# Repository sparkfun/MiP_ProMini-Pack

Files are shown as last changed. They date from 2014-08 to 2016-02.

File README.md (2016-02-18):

SparkFun MiP ProMini-Pack
===========================

SparkFun MiP ProMini-Pack

[*SparkFun MiP ProMini-Pack (DEV-13058)*](https://www.sparkfun.com/products/13058)

The MiP Robotic Platform is the first self-balancing robot that you can drive, dance, plays games, battle with other MiPs, and that you can control via a compatible iOS or Android device. 
With the SparkFun ProMini-Pack you can access the robot’s built-in hacking port to add increased functionality and a miniature Arduino to your MiP. 

Repository Contents
-------------------

* **/Hardware** - Eagle design files (.brd, .sch)
* **/Libraries** - Libraries for use with the <PRODUCT NAME>
* **/Production** - Production panel files (.brd)

Documentation
--------------
* **[Library](https://github.com/sparkfun/SparkFun_MiP_Arduino_Library)** - Arduino library for the MiP ProMini-Pack.
* **[Hookup Guide](https://learn.sparkfun.com/tutorials/hacking-the-mip---promini-pack)** - Basic hookup guide for the MiP ProMini-Pack.
* **[SparkFun Fritzing repo](https://github.com/sparkfun/Fritzing_Parts)** - Fritzing diagrams for SparkFun products.
* **[SparkFun 3D Model repo](https://github.com/sparkfun/3D_Models)** - 3D models of SparkFun products. 
* **[SparkFun Graphical Datasheets](https://github.com/sparkfun/Graphical_Datasheets)** -Graphical Datasheets for various SparkFun products.

License Information
-------------------

This product is _**open source**_! 

Please review the LICENSE.md file for license information. 

If you have any questions or concerns on licensing, please contact techsupport@sparkfun.com.

Distributed as-is; no warranty is given.

- Your friends at SparkFun.

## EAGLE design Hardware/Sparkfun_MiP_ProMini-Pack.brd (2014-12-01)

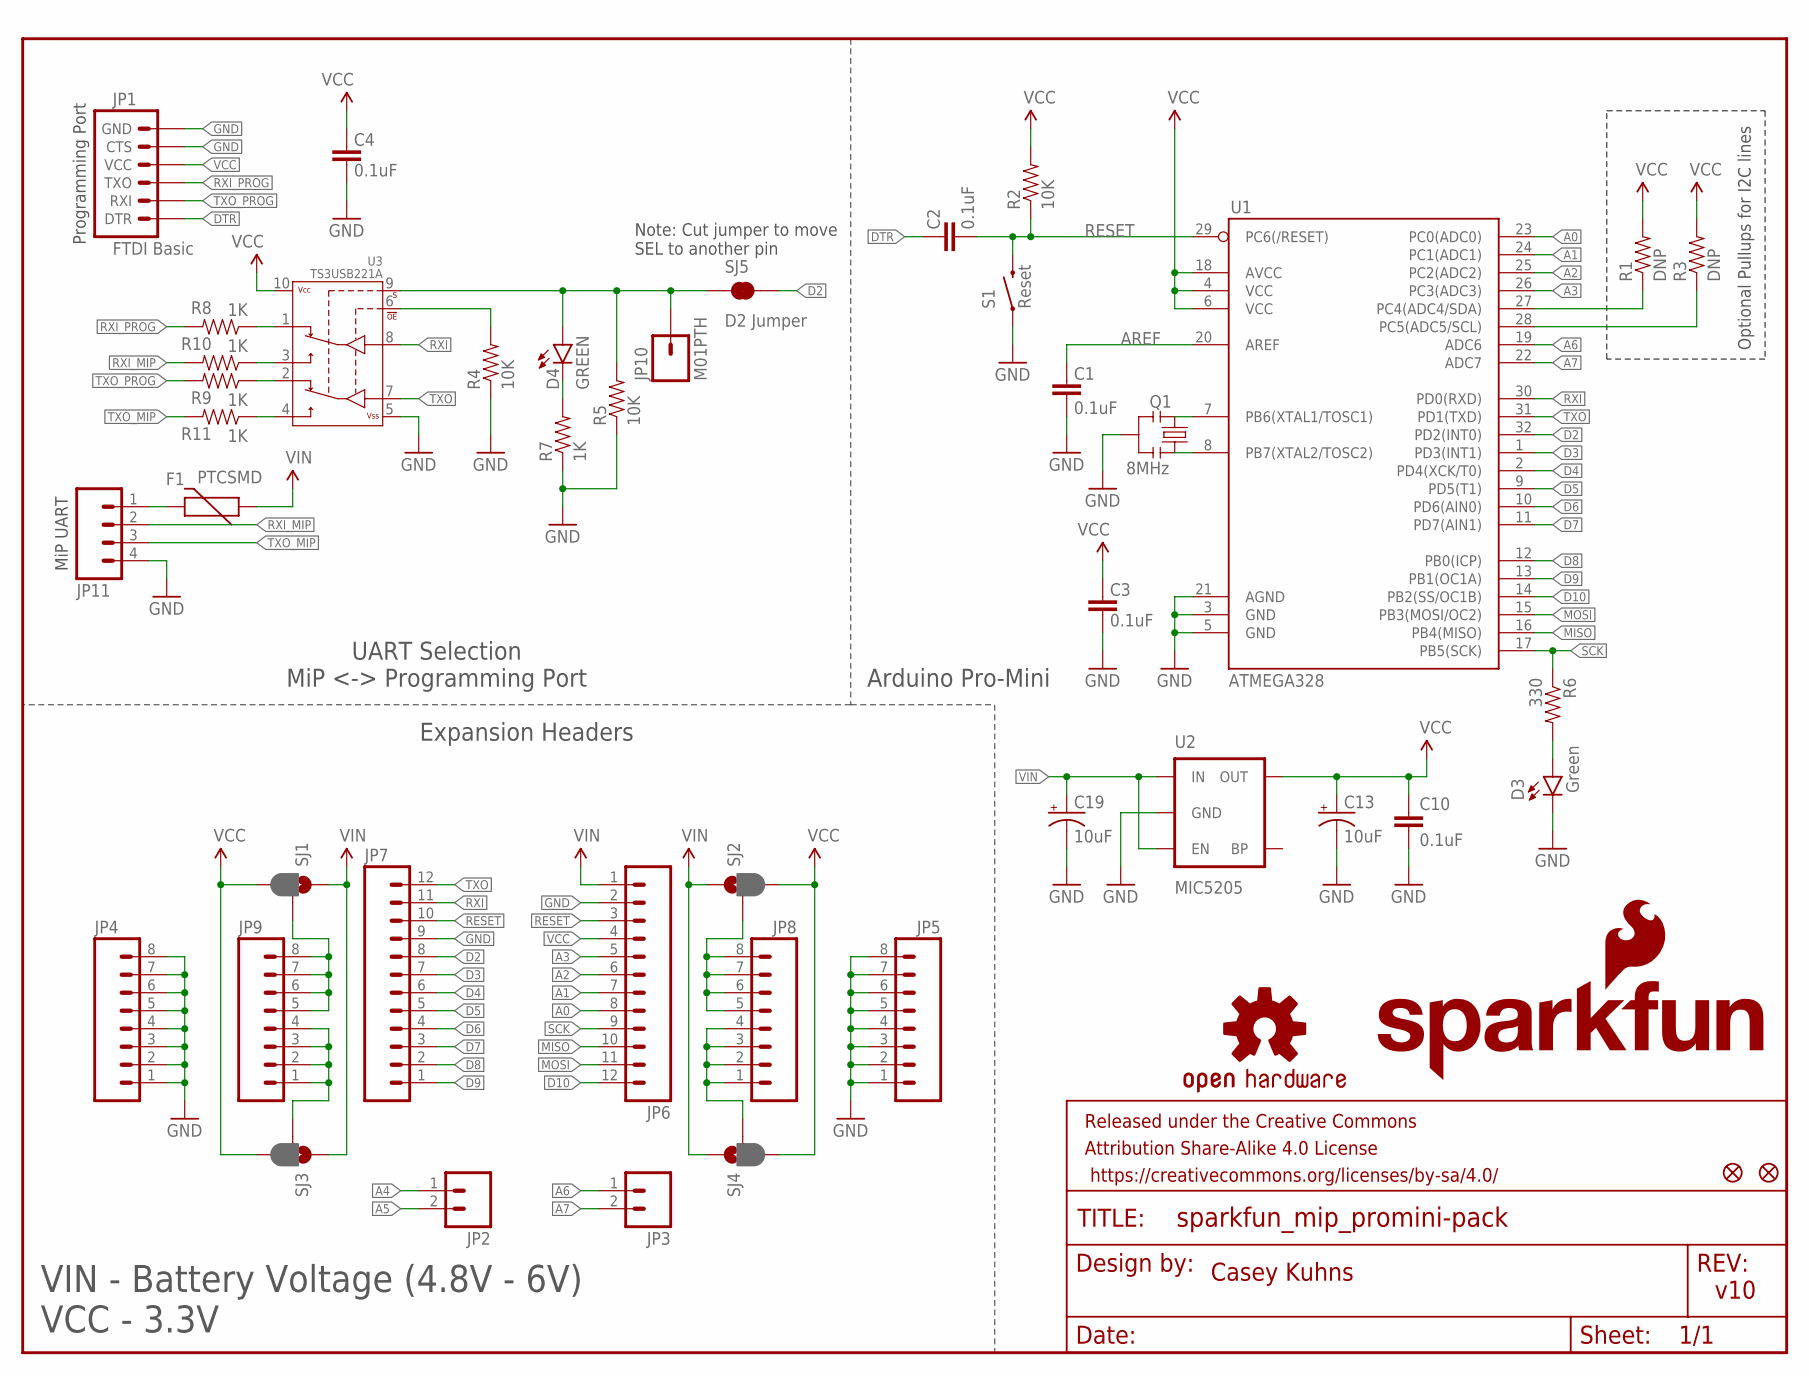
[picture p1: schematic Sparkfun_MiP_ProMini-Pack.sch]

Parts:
C1, C2, C3, C4, C10: 0.1uF; 0603-CAP
C13, C19: 10uF; EIA3216
D3: Green; LED-0603
D4: GREEN; LED-0603
F1: PTCSMD; PTC-1206
FID1, FID2: FIDUCIAL1X2; FIDUCIAL-1X2
FRAME1: FRAME-LETTER; CREATIVE_COMMONS
JP1: FTDI Basic; 1X06
JP2, JP3: M02PTH; 1X02
JP4, JP5, JP8, JP9: M081X08; 1X08
JP6, JP7: M12PTH; 1X12
JP10: M01PTH; 1X01
JP11: M04JST; 1X04-1.5MM_JST
LOGO1: SFE_LOGO_NAME_FLAME.1_INCH; SFE_LOGO_NAME_FLAME_.1
LOGO2: OSHW-LOGOS; OSHW-LOGO-S
Q1: 8MHz; RESONATOR-SMD
R1, R3: DNP; 0603-RES
R2, R4, R5: 10K; 0603-RES
R6: 330; 0603-RES
R7, R8, R9, R10, R11: 1K; 0603-RES
S1: Reset; TACTILE-SWITCH-SMD
SJ1, SJ2, SJ3, SJ4: JUMPER-PAD-3-2OF3_NC_BY_PASTE; PAD-JUMPER-3-2OF3_NC_BY_PASTE_YES_SILK_FULL_BOX
SJ5: D2 Jumper; PAD-JUMPER-2-NC_BY_TRACE_YES_SILK
U1: ATMEGA328; TQFP32-08
U2: MIC5205; SOT23-5
U3: TS3USB221A; QFN-10-RSE

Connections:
A0: JP6.8, U1.23 (PC0(ADC0))
A1: JP6.7, U1.24 (PC1(ADC1))
A2: JP6.6, U1.25 (PC2(ADC2))
A3: JP6.5, U1.26 (PC3(ADC3))
A4: JP2.1, R1.1, U1.27 (PC4(ADC4/SDA))
A5: JP2.2, R3.1, U1.28 (PC5(ADC5/SCL))
A6: JP3.1, U1.19 (ADC6)
A7: JP3.2, U1.22 (ADC7)
AREF: C1.2, U1.20 (AREF)
D2: JP7.8, SJ5.2, U1.32 (PD2(INT0))
D3: JP7.7, U1.1 (PD3(INT1))
D4: JP7.6, U1.2 (PD4(XCK/T0))
D5: JP7.5, U1.9 (PD5(T1))
D6: JP7.4, U1.10 (PD6(AIN0))
D7: JP7.3, U1.11 (PD7(AIN1))
D8: JP7.2, U1.12 (PB0(ICP))
D9: JP7.1, U1.13 (PB1(OC1A))
D10: JP6.12, U1.14 (PB2(SS/OC1B))
DTR: C2.2, JP1.1 (DTR)
GND: C1.1, C3.1, C4.1, C10.2, C13.C (-), C19.C (-), D3.C, JP1.5 (CTS), JP1.6 (GND), JP4.1, JP4.2, JP4.3, JP4.4, JP4.5, JP4.6, JP4.7, JP4.8, JP5.1, JP5.2, JP5.3, JP5.4, JP5.5, JP5.6, JP5.7, JP5.8, JP6.2, JP7.9, JP11.4, Q1.2, R4.1, R5.1, R7.1, S1.1, U1.3 (GND), U1.5 (GND), U1.21 (AGND), U2.2 (GND), U3.5 (VSS)
MISO: JP6.10, U1.16 (PB4(MISO))
MOSI: JP6.11, U1.15 (PB3(MOSI/OC2))
unnamed: Q1.3, U1.8 (PB7(XTAL2/TOSC2))
unnamed: JP9.5, JP9.6, JP9.7, JP9.8, SJ1.2
unnamed: JP9.1, JP9.2, JP9.3, JP9.4, SJ3.2
unnamed: Q1.1, U1.7 (PB6(XTAL1/TOSC1))
unnamed: JP8.5, JP8.6, JP8.7, JP8.8, SJ2.2
unnamed: JP8.1, JP8.2, JP8.3, JP8.4, SJ4.2
unnamed: D3.A, R6.2
unnamed: D4.C, R7.2
unnamed: R10.1, U3.3 (2D+)
unnamed: R11.1, U3.4 (2D-)
unnamed: R8.1, U3.1 (1D+)
unnamed: R4.2, U3.6 (!OE)
unnamed: R9.1, U3.2 (1D-)
unnamed: F1.2, JP11.1
RESET: C2.1, JP6.3, JP7.10, R2.1, S1.3 (2), U1.29 (PC6(/RESET))
RXI: JP7.11, U1.30 (PD0(RXD)), U3.8 (D+)
RXI_MIP: JP11.2, R10.2
RXI_PROG: JP1.3 (TXO), R8.2
SCK: JP6.9, R6.1, U1.17 (PB5(SCK))
SELECT: D4.A, JP10.1, R5.2, SJ5.1, U3.9 (S)
TXO: JP7.12, U1.31 (PD1(TXD)), U3.7 (D-)
TXO_MIP: JP11.3, R11.2
TXO_PROG: JP1.2 (RXI), R9.2
VCC: C3.2, C4.2, C10.1, C13.A (+), JP1.4 (VCC), JP6.4, R1.2, R2.2, R3.2, SJ1.3, SJ2.3, SJ3.3, SJ4.3, U1.4 (VCC), U1.6 (VCC), U1.18 (AVCC), U2.5 (OUT), U3.10 (VCC)
VIN: C19.A (+), F1.1, JP6.1, SJ1.1, SJ2.1, SJ3.1, SJ4.1, U2.1 (IN), U2.3 (EN)

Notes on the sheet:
Optional Pullups for I2C lines
Casey Kuhns
v10
Note: Cut jumper to move SEL to another pin
MiP UART
Programming Port
UART Selection MiP <-> Programming Port
Expansion Headers
Arduino Pro-Mini
VIN - Battery Voltage (4.8V - 6V) VCC - 3.3V

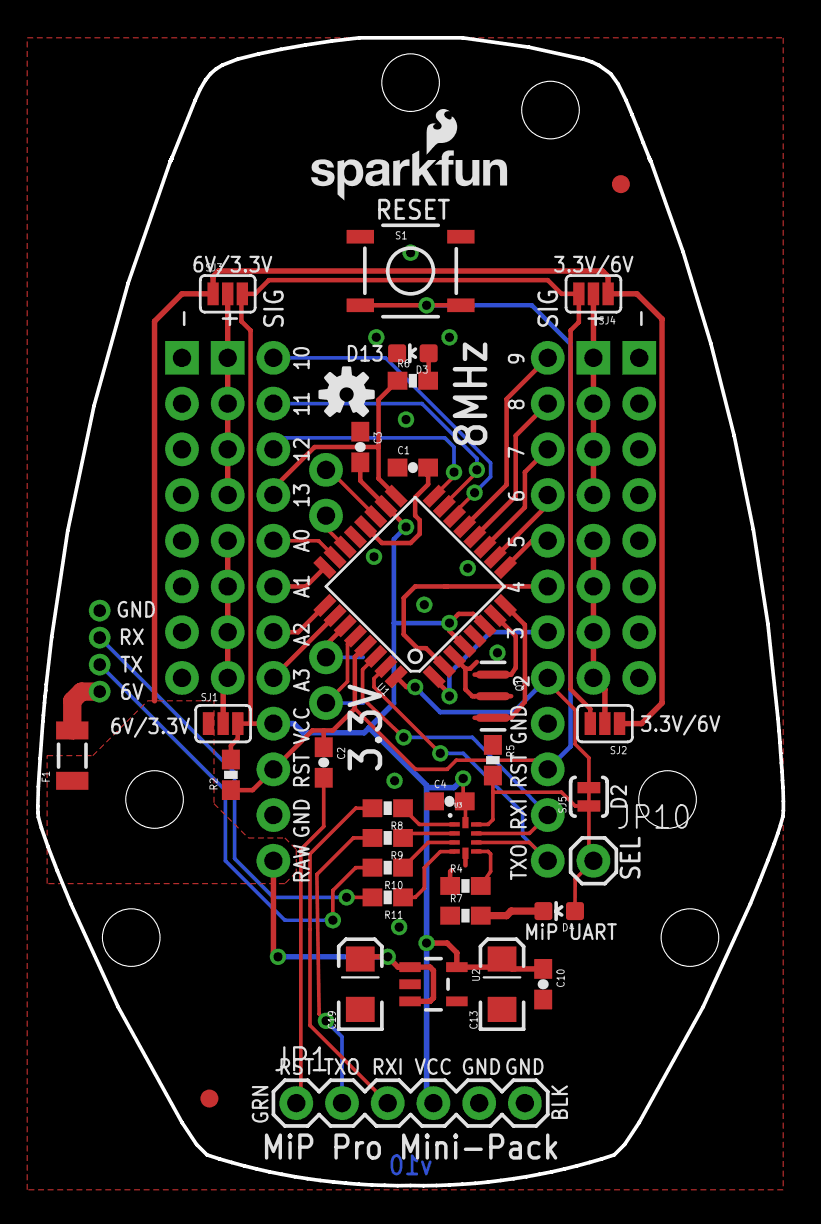
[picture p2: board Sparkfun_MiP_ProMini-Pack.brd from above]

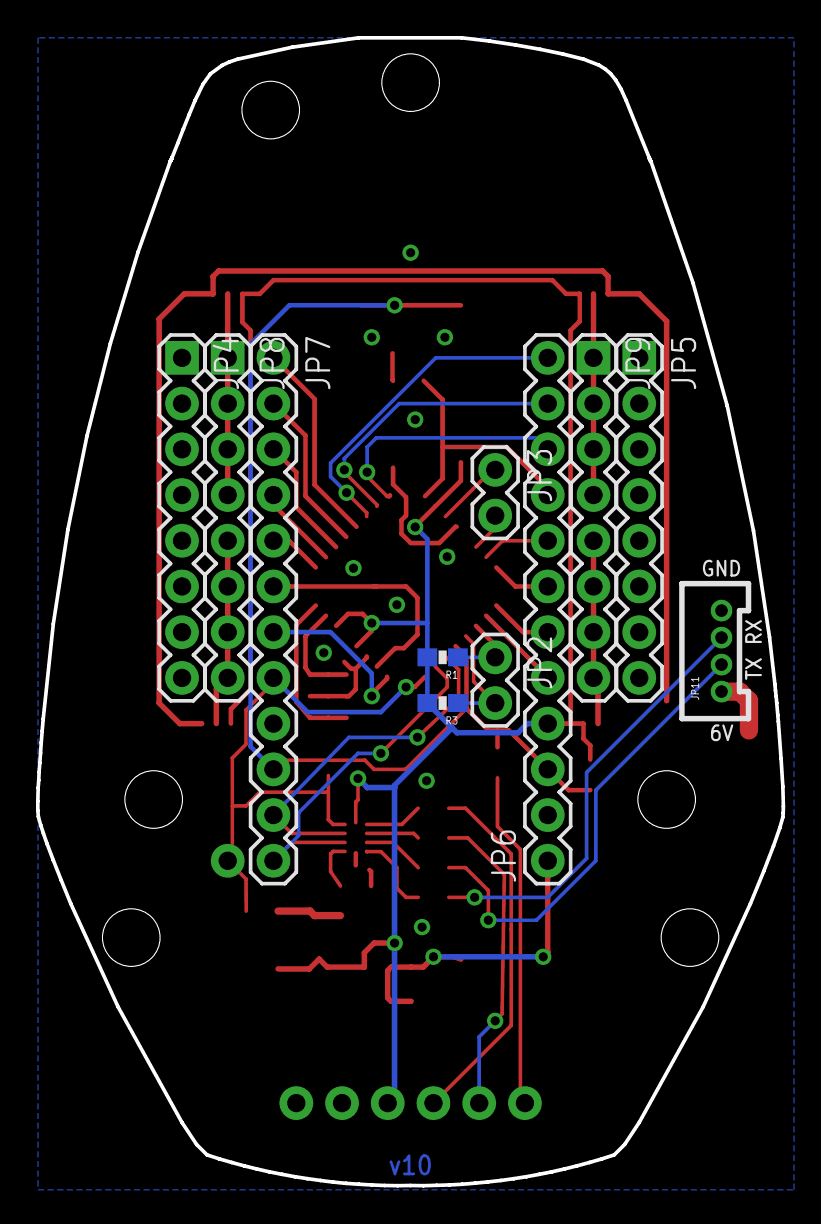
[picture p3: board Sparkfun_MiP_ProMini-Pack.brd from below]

Board: 2 copper layers, 41.4 x 63.8 mm, 47 parts (11 on the bottom side), 47 nets.

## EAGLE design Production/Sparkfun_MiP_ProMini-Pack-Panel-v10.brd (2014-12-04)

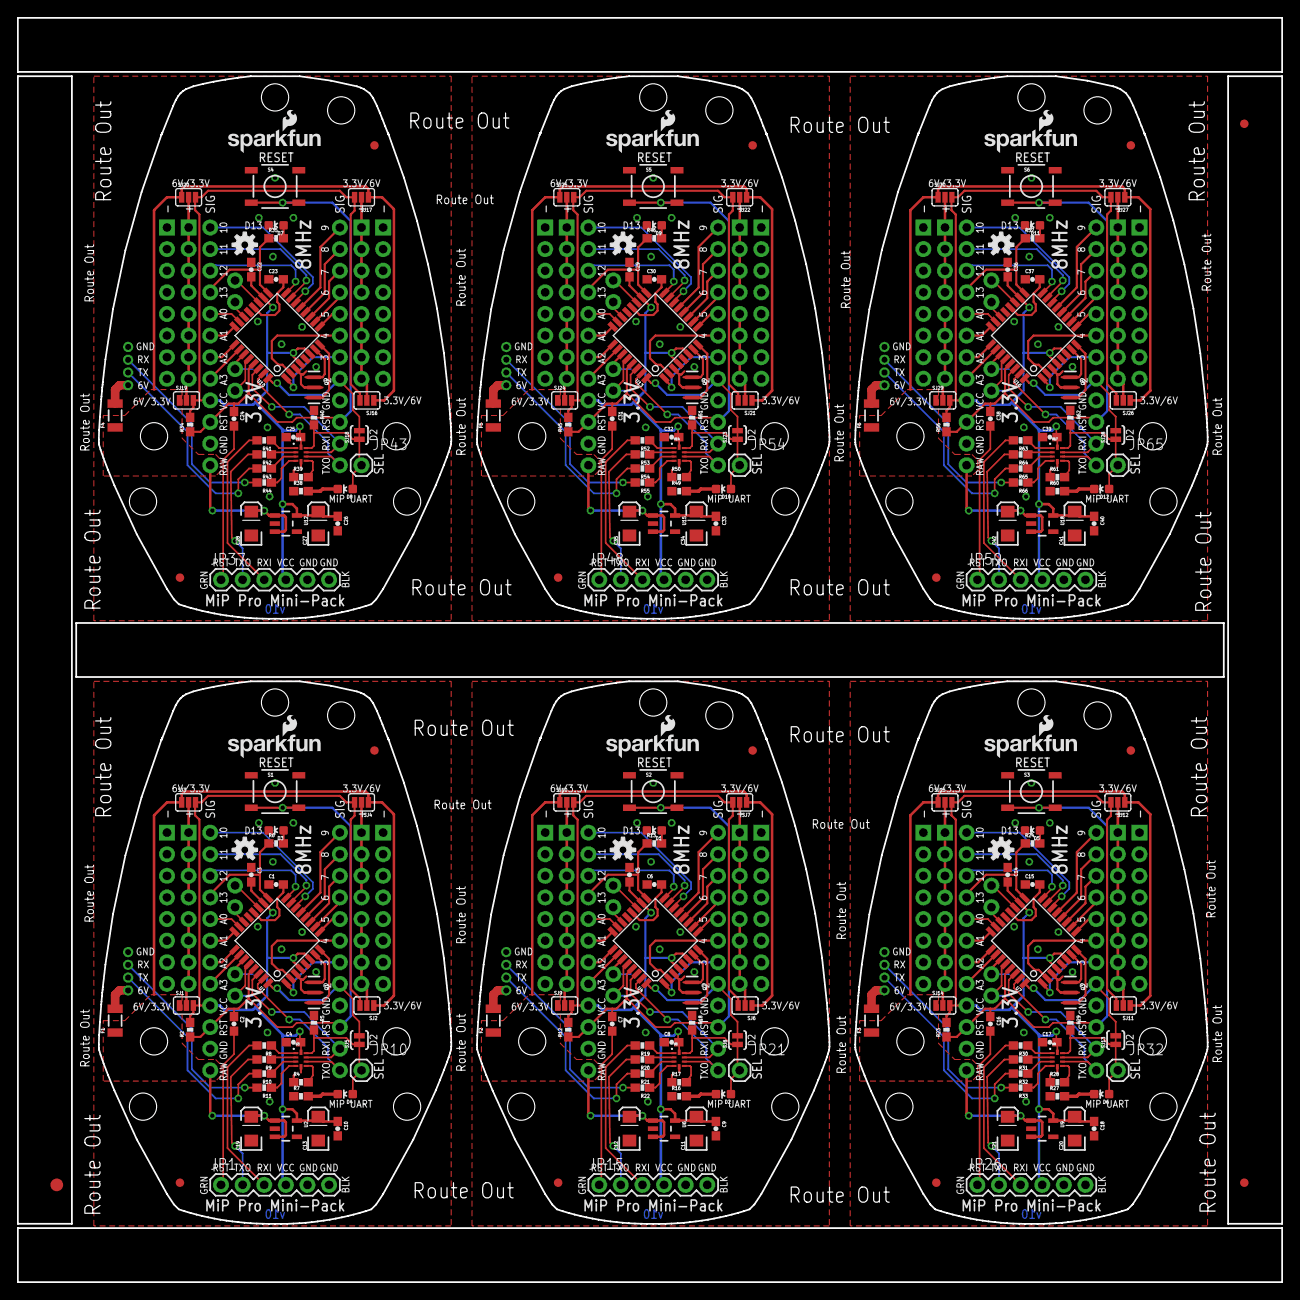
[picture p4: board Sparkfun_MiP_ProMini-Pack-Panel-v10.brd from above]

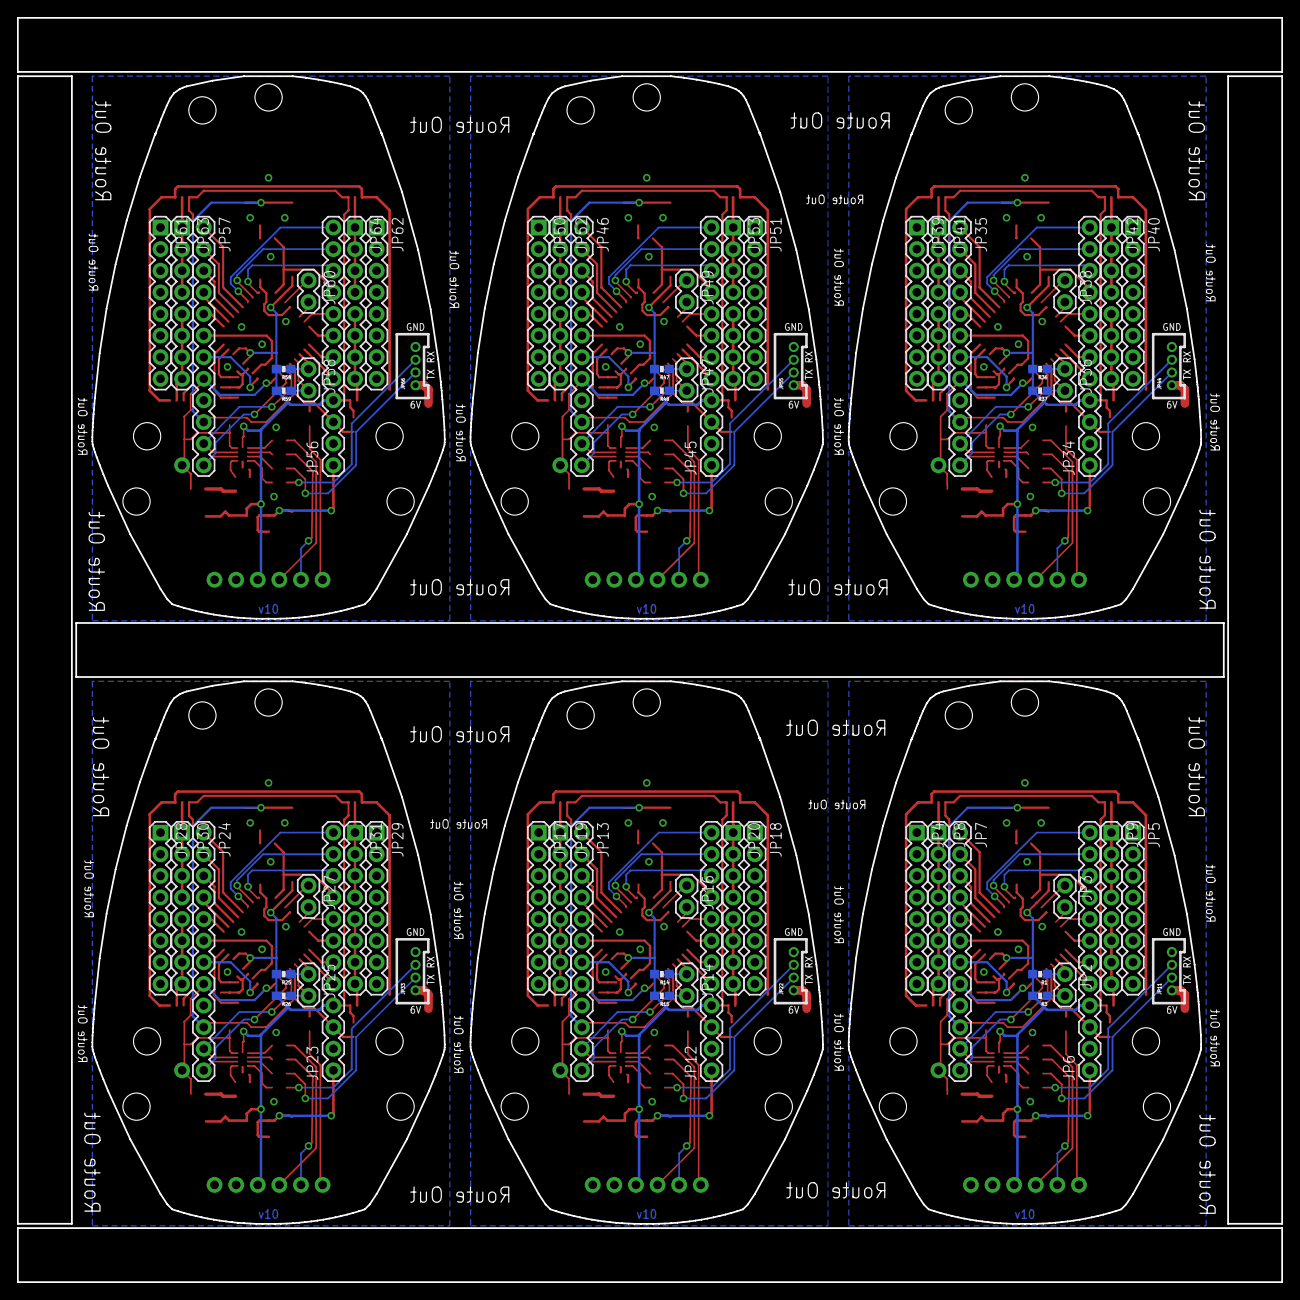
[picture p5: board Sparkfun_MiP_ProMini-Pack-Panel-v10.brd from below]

Board: 2 copper layers, 148.6 x 148.6 mm, 279 parts (66 on the bottom side), 282 nets.

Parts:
C1, C2, C3, C4, C5, C6, C7, C8, C9, C10, C14, C15, C16, C17, C18, C22, C23, C24, C25, C26, C29, C30, C31, C32, C33, C36, C37, C38, C39, C40: 0.1uF; 0603-CAP
C11, C12, C13, C19, C20, C21, C27, C28, C34, C35, C41, C42: 10uF; EIA3216
D1, D3, D5, D7, D9, D11: Green; LED-0603
D2, D4, D6, D8, D10, D12: GREEN; LED-0603
E$1: FIDUCIAL-1.5X3
E$4, E$10: FIDUCIAL-1X2
F1, F2, F3, F4, F5, F6: PTCSMD; PTC-1206
FID1, FID2, FID3, FID4, FID5, FID6, FID7, FID8, FID9, FID10, FID11, FID12: FIDUCIAL1X2; FIDUCIAL-1X2
JP1, JP15, JP26, JP37, JP48, JP59: FTDI Basic; 1X06
JP2, JP3, JP14, JP16, JP25, JP27, JP36, JP38, JP47, JP49, JP58, JP60: 1X02
JP4, JP5, JP8, JP9, JP17, JP18, JP19, JP20, JP28, JP29, JP30, JP31, JP39, JP40, JP41, JP42, JP50, JP51, JP52, JP53, JP61, JP62, JP63, JP64: 1X08
JP6, JP7, JP12, JP13, JP23, JP24, JP34, JP35, JP45, JP46, JP56, JP57: 1X12
JP10, JP21, JP32, JP43, JP54, JP65: M01PTH; 1X01
JP11, JP22, JP33, JP44, JP55, JP66: 1X04-1.5MM_JST
LOGO1, LOGO3, LOGO5, LOGO7, LOGO9, LOGO11: SFE_LOGO_NAME_FLAME.1_INCH; SFE_LOGO_NAME_FLAME_.1
LOGO2, LOGO4, LOGO6, LOGO8, LOGO10, LOGO12: OSHW-LOGOS; OSHW-LOGO-S
Q1, Q2, Q3, Q4, Q5, Q6: 8MHz; RESONATOR-SMD
R1, R3, R14, R15, R25, R26, R36, R37, R47, R48, R58, R59: DNP; 0603-RES
R2, R4, R5, R12, R17, R18, R23, R28, R29, R34, R39, R40, R45, R50, R51, R56, R61, R62: 10K; 0603-RES
R6, R13, R24, R35, R46, R57: 330; 0603-RES
R7, R8, R9, R10, R11, R16, R19, R20, R21, R22, R27, R30, R31, R32, R33, R38, R41, R42, R43, R44, R49, R52, R53, R54, R55, R60, R63, R64, R65, R66: 1K; 0603-RES
S1, S2, S3, S4, S5, S6: Reset; TACTILE-SWITCH-SMD
SJ1, SJ2, SJ3, SJ4, SJ6, SJ7, SJ9, SJ10, SJ11, SJ12, SJ14, SJ15, SJ16, SJ17, SJ19, SJ20, SJ21, SJ22, SJ24, SJ25, SJ26, SJ27, SJ29, SJ30: PAD-JUMPER-3-2OF3_NC_BY_PASTE_YES_SILK_FULL_BOX
SJ5, SJ8, SJ13, SJ18, SJ23, SJ28: D2 Jumper; PAD-JUMPER-2-NC_BY_TRACE_YES_SILK
U1, U4, U7, U10, U13, U16: ATMEGA328; TQFP32-08
U2, U6, U9, U12, U15, U18: MIC5205; SOT23-5
U3, U5, U8, U11, U14, U17: TS3USB221A; QFN-10-RSE

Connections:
A0: JP6.8, U1.23
A1: JP6.7, U1.24
A2: JP6.6, U1.25
A3: JP6.5, U1.26
A4: JP2.1, R1.1, U1.27
A5: JP2.2, R3.1, U1.28
A6: JP3.1, U1.19
A7: JP3.2, U1.22
A8: JP14.2, R15.1, U4.28
A9: JP14.1, R14.1, U4.27
A10: JP12.5, U4.26
A11: JP12.6, U4.25
A12: JP12.7, U4.24
A13: JP12.8, U4.23
A14: JP16.1, U4.19
A15: JP16.2, U4.22
A16: JP25.2, R26.1, U7.28
A17: JP25.1, R25.1, U7.27
A18: JP23.5, U7.26
A19: JP23.6, U7.25
A20: JP23.7, U7.24
A21: JP23.8, U7.23
A22: JP27.1, U7.19
A23: JP27.2, U7.22
A24: JP36.2, R37.1, U10.28
A25: JP36.1, R36.1, U10.27
A26: JP34.5, U10.26
A27: JP34.6, U10.25
A28: JP34.7, U10.24
A29: JP34.8, U10.23
A30: JP38.1, U10.19
A31: JP38.2, U10.22
A32: JP47.2, R48.1, U13.28
A33: JP47.1, R47.1, U13.27
A34: JP45.5, U13.26
A35: JP45.6, U13.25
A36: JP45.7, U13.24
A37: JP45.8, U13.23
A38: JP49.1, U13.19
A39: JP49.2, U13.22
A40: JP58.2, R59.1, U16.28
A41: JP58.1, R58.1, U16.27
A42: JP56.5, U16.26
A43: JP56.6, U16.25
A44: JP56.7, U16.24
A45: JP56.8, U16.23
A46: JP60.1, U16.19
A47: JP60.2, U16.22
AREF: C1.2, U1.20
AREF1: C6.2, U4.20
AREF2: C15.2, U7.20
AREF3: C23.2, U10.20
AREF4: C30.2, U13.20
AREF5: C37.2, U16.20
D1: JP13.1, U4.13
D2: JP7.8, SJ5.2, U1.32
D3: JP7.7, U1.1
D4: JP7.6, U1.2
D5: JP7.5, U1.9
D6: JP7.4, U1.10
D7: JP7.3, U1.11
D8: JP7.2, U1.12
D9: JP7.1, U1.13
D10: JP6.12, U1.14
D11: JP13.2, U4.12
D12: JP13.8, SJ8.2, U4.32
D13: JP13.7, U4.1
D14: JP13.6, U4.2
D15: JP13.5, U4.9
D16: JP13.4, U4.10
D17: JP13.3, U4.11
D18: JP12.12, U4.14
D19: JP24.1, U7.13
D20: JP24.2, U7.12
D21: JP24.8, SJ13.2, U7.32
D22: JP24.7, U7.1
D23: JP24.6, U7.2
D24: JP24.5, U7.9
D25: JP24.4, U7.10
D26: JP24.3, U7.11
D27: JP23.12, U7.14
D28: JP35.1, U10.13
D29: JP35.2, U10.12
D30: JP35.8, SJ18.2, U10.32
D31: JP35.7, U10.1
D32: JP35.6, U10.2
D33: JP35.5, U10.9
D34: JP35.4, U10.10
D35: JP35.3, U10.11
D36: JP34.12, U10.14
D37: JP46.1, U13.13
D38: JP46.2, U13.12
D39: JP46.8, SJ23.2, U13.32
D40: JP46.7, U13.1
D41: JP46.6, U13.2
D42: JP46.5, U13.9
D43: JP46.4, U13.10
D44: JP46.3, U13.11
D45: JP45.12, U13.14
D46: JP57.1, U16.13
D47: JP57.2, U16.12
D48: JP57.8, SJ28.2, U16.32
D49: JP57.7, U16.1
D50: JP57.6, U16.2
D51: JP57.5, U16.9
D52: JP57.4, U16.10
D53: JP57.3, U16.11
D54: JP56.12, U16.14
DTR: C2.2, JP1.1
DTR1: C7.2, JP15.1
DTR2: C16.2, JP26.1
DTR3: C24.2, JP37.1
DTR4: C31.2, JP48.1
DTR5: C38.2, JP59.1
GND: C1.1, C3.1, C4.1, C10.2, C13.C, C19.C, D3.C, JP1.5, JP1.6, JP4.1, JP4.2, JP4.3, JP4.4, JP4.5, JP4.6, JP4.7, JP4.8, JP5.1, JP5.2, JP5.3, JP5.4, JP5.5, JP5.6, JP5.7, JP5.8, JP6.2, JP7.9, JP11.4, Q1.2, R4.1, R5.1, R7.1, S1.1, U1.3, U1.5, U1.21, U2.2, U3.5
GND1: C5.1, C6.1, C8.1, C9.2, C11.C, C12.C, D1.C, JP12.2, JP13.9, JP15.5, JP15.6, JP17.1, JP17.2, JP17.3, JP17.4, JP17.5, JP17.6, JP17.7, JP17.8, JP18.1, JP18.2, JP18.3, JP18.4, JP18.5, JP18.6, JP18.7, JP18.8, JP22.4, Q2.2, R16.1, R17.1, R18.1, S2.1, U4.3, U4.5, U4.21, U5.5, U6.2
GND2: C14.1, C15.1, C17.1, C18.2, C20.C, C21.C, D5.C, JP23.2, JP24.9, JP26.5, JP26.6, JP28.1, JP28.2, JP28.3, JP28.4, JP28.5, JP28.6, JP28.7, JP28.8, JP29.1, JP29.2, JP29.3, JP29.4, JP29.5, JP29.6, JP29.7, JP29.8, JP33.4, Q3.2, R27.1, R28.1, R29.1, S3.1, U7.3, U7.5, U7.21, U8.5, U9.2
GND3: C22.1, C23.1, C25.1, C26.2, C27.C, C28.C, D7.C, JP34.2, JP35.9, JP37.5, JP37.6, JP39.1, JP39.2, JP39.3, JP39.4, JP39.5, JP39.6, JP39.7, JP39.8, JP40.1, JP40.2, JP40.3, JP40.4, JP40.5, JP40.6, JP40.7, JP40.8, JP44.4, Q4.2, R38.1, R39.1, R40.1, S4.1, U10.3, U10.5, U10.21, U11.5, U12.2
GND4: C29.1, C30.1, C32.1, C33.2, C34.C, C35.C, D9.C, JP45.2, JP46.9, JP48.5, JP48.6, JP50.1, JP50.2, JP50.3, JP50.4, JP50.5, JP50.6, JP50.7, JP50.8, JP51.1, JP51.2, JP51.3, JP51.4, JP51.5, JP51.6, JP51.7, JP51.8, JP55.4, Q5.2, R49.1, R50.1, R51.1, S5.1, U13.3, U13.5, U13.21, U14.5, U15.2
GND5: C36.1, C37.1, C39.1, C40.2, C41.C, C42.C, D11.C, JP56.2, JP57.9, JP59.5, JP59.6, JP61.1, JP61.2, JP61.3, JP61.4, JP61.5, JP61.6, JP61.7, JP61.8, JP62.1, JP62.2, JP62.3, JP62.4, JP62.5, JP62.6, JP62.7, JP62.8, JP66.4, Q6.2, R60.1, R61.1, R62.1, S6.1, U16.3, U16.5, U16.21, U17.5, U18.2
MISO: JP6.10, U1.16
MISO1: JP12.10, U4.16
MISO2: JP23.10, U7.16
MISO3: JP34.10, U10.16
MISO4: JP45.10, U13.16
MISO5: JP56.10, U16.16
MOSI: JP6.11, U1.15
MOSI1: JP12.11, U4.15
MOSI2: JP23.11, U7.15
MOSI3: JP34.11, U10.15
MOSI4: JP45.11, U13.15
MOSI5: JP56.11, U16.15
unnamed: Q1.3, U1.8
unnamed: JP9.5, JP9.6, JP9.7, JP9.8, SJ1.2
unnamed: JP9.1, JP9.2, JP9.3, JP9.4, SJ3.2
unnamed: Q1.1, U1.7
unnamed: JP8.5, JP8.6, JP8.7, JP8.8, SJ2.2
unnamed: JP8.1, JP8.2, JP8.3, JP8.4, SJ4.2
unnamed: D3.A, R6.2
unnamed: D4.C, R7.2
unnamed: R10.1, U3.3
unnamed: R11.1, U3.4
unnamed: R8.1, U3.1
unnamed: R4.2, U3.6
unnamed: R9.1, U3.2
unnamed: D1.A, R13.2
unnamed: Q2.3, U4.8
unnamed: F1.2, JP11.1
unnamed: Q2.1, U4.7
unnamed: JP19.5, JP19.6, JP19.7, JP19.8, SJ6.2
unnamed: JP20.5, JP20.6, JP20.7, JP20.8, SJ9.2
unnamed: JP20.1, JP20.2, JP20.3, JP20.4, SJ10.2
unnamed: JP19.1, JP19.2, JP19.3, JP19.4, SJ7.2
unnamed: D2.C, R16.2
unnamed: R17.2, U5.6
unnamed: R19.1, U5.1
unnamed: R20.1, U5.2
unnamed: R21.1, U5.3
unnamed: R22.1, U5.4
unnamed: F2.2, JP22.1
unnamed: D5.A, R24.2
unnamed: Q3.3, U7.8
unnamed: Q3.1, U7.7
unnamed: JP30.5, JP30.6, JP30.7, JP30.8, SJ11.2
unnamed: JP31.5, JP31.6, JP31.7, JP31.8, SJ14.2
unnamed: JP31.1, JP31.2, JP31.3, JP31.4, SJ15.2
unnamed: JP30.1, JP30.2, JP30.3, JP30.4, SJ12.2
unnamed: D6.C, R27.2
unnamed: R28.2, U8.6
unnamed: R30.1, U8.1
unnamed: R31.1, U8.2
unnamed: R32.1, U8.3
unnamed: R33.1, U8.4
unnamed: F3.2, JP33.1
unnamed: D7.A, R35.2
unnamed: Q4.3, U10.8
unnamed: Q4.1, U10.7
unnamed: JP41.5, JP41.6, JP41.7, JP41.8, SJ16.2
unnamed: JP42.5, JP42.6, JP42.7, JP42.8, SJ19.2
unnamed: JP42.1, JP42.2, JP42.3, JP42.4, SJ20.2
unnamed: JP41.1, JP41.2, JP41.3, JP41.4, SJ17.2
unnamed: D8.C, R38.2
unnamed: R39.2, U11.6
unnamed: R41.1, U11.1
unnamed: R42.1, U11.2
unnamed: R43.1, U11.3
unnamed: R44.1, U11.4
unnamed: F4.2, JP44.1
unnamed: D9.A, R46.2
unnamed: Q5.3, U13.8
unnamed: Q5.1, U13.7
unnamed: JP52.5, JP52.6, JP52.7, JP52.8, SJ21.2
unnamed: JP53.5, JP53.6, JP53.7, JP53.8, SJ24.2
unnamed: JP53.1, JP53.2, JP53.3, JP53.4, SJ25.2
unnamed: JP52.1, JP52.2, JP52.3, JP52.4, SJ22.2
unnamed: D10.C, R49.2
unnamed: R50.2, U14.6
unnamed: R52.1, U14.1
unnamed: R53.1, U14.2
unnamed: R54.1, U14.3
unnamed: R55.1, U14.4
unnamed: F5.2, JP55.1
unnamed: D11.A, R57.2
unnamed: Q6.3, U16.8
unnamed: Q6.1, U16.7
unnamed: JP63.5, JP63.6, JP63.7, JP63.8, SJ26.2
unnamed: JP64.5, JP64.6, JP64.7, JP64.8, SJ29.2
unnamed: JP64.1, JP64.2, JP64.3, JP64.4, SJ30.2
unnamed: JP63.1, JP63.2, JP63.3, JP63.4, SJ27.2
unnamed: D12.C, R60.2
unnamed: R61.2, U17.6
unnamed: R63.1, U17.1
unnamed: R64.1, U17.2
unnamed: R65.1, U17.3
unnamed: R66.1, U17.4
unnamed: F6.2, JP66.1
RESET: C2.1, JP6.3, JP7.10, R2.1, S1.3, U1.29
RESET1: C7.1, JP12.3, JP13.10, R12.1, S2.3, U4.29
RESET2: C16.1, JP23.3, JP24.10, R23.1, S3.3, U7.29
RESET3: C24.1, JP34.3, JP35.10, R34.1, S4.3, U10.29
RESET4: C31.1, JP45.3, JP46.10, R45.1, S5.3, U13.29
RESET5: C38.1, JP56.3, JP57.10, R56.1, S6.3, U16.29
RXI: JP7.11, U1.30, U3.8
RXI1: JP13.11, U4.30, U5.8
RXI2: JP24.11, U7.30, U8.8
RXI3: JP35.11, U10.30, U11.8
RXI4: JP46.11, U13.30, U14.8
RXI5: JP57.11, U16.30, U17.8
RXI_MIP: JP11.2, R10.2
RXI_MIP1: JP22.2, R21.2
RXI_MIP2: JP33.2, R32.2
RXI_MIP3: JP44.2, R43.2
RXI_MIP4: JP55.2, R54.2
RXI_MIP5: JP66.2, R65.2
RXI_PROG: JP1.3, R8.2
RXI_PROG1: JP15.3, R19.2
RXI_PROG2: JP26.3, R30.2
RXI_PROG3: JP37.3, R41.2
RXI_PROG4: JP48.3, R52.2
RXI_PROG5: JP59.3, R63.2
SCK: JP6.9, R6.1, U1.17
SCK1: JP12.9, R13.1, U4.17
SCK2: JP23.9, R24.1, U7.17
SCK3: JP34.9, R35.1, U10.17
SCK4: JP45.9, R46.1, U13.17
SCK5: JP56.9, R57.1, U16.17
SELECT: D4.A, JP10.1, R5.2, SJ5.1, U3.9
SELECT1: D2.A, JP21.1, R18.2, SJ8.1, U5.9
SELECT2: D6.A, JP32.1, R29.2, SJ13.1, U8.9
SELECT3: D8.A, JP43.1, R40.2, SJ18.1, U11.9
SELECT4: D10.A, JP54.1, R51.2, SJ23.1, U14.9
SELECT5: D12.A, JP65.1, R62.2, SJ28.1, U17.9
TXO: JP7.12, U1.31, U3.7
TXO1: JP13.12, U4.31, U5.7
TXO2: JP24.12, U7.31, U8.7
TXO3: JP35.12, U10.31, U11.7
TXO4: JP46.12, U13.31, U14.7
TXO5: JP57.12, U16.31, U17.7
TXO_MIP: JP11.3, R11.2
TXO_MIP1: JP22.3, R22.2
TXO_MIP2: JP33.3, R33.2
TXO_MIP3: JP44.3, R44.2
TXO_MIP4: JP55.3, R55.2
TXO_MIP5: JP66.3, R66.2
TXO_PROG: JP1.2, R9.2
TXO_PROG1: JP15.2, R20.2
TXO_PROG2: JP26.2, R31.2
TXO_PROG3: JP37.2, R42.2
TXO_PROG4: JP48.2, R53.2
TXO_PROG5: JP59.2, R64.2
VCC: C3.2, C4.2, C10.1, C13.A, JP1.4, JP6.4, R1.2, R2.2, R3.2, SJ1.3, SJ2.3, SJ3.3, SJ4.3, U1.4, U1.6, U1.18, U2.5, U3.10
VCC1: C5.2, C8.2, C9.1, C11.A, JP12.4, JP15.4, R12.2, R14.2, R15.2, SJ6.3, SJ7.3, SJ9.3, SJ10.3, U4.4, U4.6, U4.18, U5.10, U6.5
VCC2: C14.2, C17.2, C18.1, C20.A, JP23.4, JP26.4, R23.2, R25.2, R26.2, SJ11.3, SJ12.3, SJ14.3, SJ15.3, U7.4, U7.6, U7.18, U8.10, U9.5
VCC3: C22.2, C25.2, C26.1, C27.A, JP34.4, JP37.4, R34.2, R36.2, R37.2, SJ16.3, SJ17.3, SJ19.3, SJ20.3, U10.4, U10.6, U10.18, U11.10, U12.5
VCC4: C29.2, C32.2, C33.1, C34.A, JP45.4, JP48.4, R45.2, R47.2, R48.2, SJ21.3, SJ22.3, SJ24.3, SJ25.3, U13.4, U13.6, U13.18, U14.10, U15.5
VCC5: C36.2, C39.2, C40.1, C41.A, JP56.4, JP59.4, R56.2, R58.2, R59.2, SJ26.3, SJ27.3, SJ29.3, SJ30.3, U16.4, U16.6, U16.18, U17.10, U18.5
VIN: C19.A, F1.1, JP6.1, SJ1.1, SJ2.1, SJ3.1, SJ4.1, U2.1, U2.3
VIN1: C12.A, F2.1, JP12.1, SJ6.1, SJ7.1, SJ9.1, SJ10.1, U6.1, U6.3
VIN2: C21.A, F3.1, JP23.1, SJ11.1, SJ12.1, SJ14.1, SJ15.1, U9.1, U9.3
VIN3: C28.A, F4.1, JP34.1, SJ16.1, SJ17.1, SJ19.1, SJ20.1, U12.1, U12.3
VIN4: C35.A, F5.1, JP45.1, SJ21.1, SJ22.1, SJ24.1, SJ25.1, U15.1, U15.3
VIN5: C42.A, F6.1, JP56.1, SJ26.1, SJ27.1, SJ29.1, SJ30.1, U18.1, U18.3

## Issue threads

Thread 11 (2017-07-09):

ATmega328p@8MHz can't do 115200 baud

Tiogaplanet, 2017-07-09:
The MiP's UART  port only works at 115200 and the ATmega328p@8MHz can't read long strings from the MiP at 115200.  It works OK for one or two bytes then the data starts getting corrupted.  This board should be built around the ATmega328p@16MHz and 5V.

I've purchased the Arduino Pro Mini 5V/16MHz to continue developing the SparkFun MiP Arduino library.  The library should be pretty portable between the MiP ProMini Pack and the Arduino Pro Mini 5V/16MHz.

adamgreen, 2018-04-26:
Now testing a new 5V/16MHz version of the MiP ProMini Pack design from [over here](https://github.com/adamgreen/MiP_ProMini-Pack#readme) with a new more feature complete [Arduino library](https://github.com/adamgreen/MiP_ProMini-Pack/tree/master/Arduino/MiP_ProMini_Pack_Library).

Tiogaplanet, 2018-09-04:
Long overdue to close this.  Confirmed ATmega328p@8MHz not suited to 115200bps.  Switch to 5V/16MHz version solves the problem.

Closed 2018-09-04.

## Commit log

2014-08-19 initial commit ready for review
    [MiP_Mini-Pack.brd, MiP_Mini-Pack.sch]
2014-08-19 corrected labels, ready for review
    [MiP_Mini-Pack.brd, MiP_Mini-Pack.sch]
2014-08-20 made silk changes and renamed board files to match repo name
    [MiP_ProMini-Pack.brd, MiP_ProMini-Pack.sch]
2014-11-10 moved components near screw holes. Gives more clearance for hardware
    [MiP_ProMini-Pack.brd]
2014-11-17 renamed files
    [Sparkfun_MiP_ProMini-Pack.brd, Sparkfun_MiP_ProMini-Pack.sch]
2014-11-17 added lables to servo pins to show pin modes
    [Sparkfun_MiP_ProMini-Pack.brd]
2014-11-18 addressing issues in github
    [Sparkfun_MiP_ProMini-Pack.brd, Sparkfun_MiP_ProMini-Pack.sch]
2014-11-18 added ProdID's to parts
    [Sparkfun_MiP_ProMini-Pack.brd, Sparkfun_MiP_ProMini-Pack.sch]
2014-12-01 corrected isolate to 12mil made some layout changes to accomidate.
    [Sparkfun_MiP_ProMini-Pack.brd]
2014-12-04 created panel v10
    [Sparkfun_MiP_ProMini-Pack-Panel-v10.brd]
2016-02-18 Updating directory structure, fixing README, adding license
    [Sparkfun_MiP_ProMini-Pack-Panel-v10.brd]
2016-02-18 Squashed 'Libraries/Arduino/' content from commit 2675813
    git-subtree-dir: Libraries/Arduino
    git-subtree-split: 2675813431cdc92eb685581f2a9a0be69a096b4c

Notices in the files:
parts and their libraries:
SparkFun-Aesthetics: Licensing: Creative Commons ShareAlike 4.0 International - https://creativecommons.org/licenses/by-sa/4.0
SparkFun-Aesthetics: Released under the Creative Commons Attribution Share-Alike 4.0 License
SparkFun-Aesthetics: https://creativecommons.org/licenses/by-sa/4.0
